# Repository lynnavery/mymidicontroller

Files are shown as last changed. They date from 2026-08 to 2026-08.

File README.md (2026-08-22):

# mymidicontroller
Simple 9 knob 10 key midi controller design using teensy and no mux/adc expanders

## Mockup

## BOM
| Qty | Part |
|---|---|
| 1 | Teensy 4.1 with headers |
| 2 | Custom PCB
| 1 | Jumper wires Female/Male 300mm pack of 40 |
| 1 | Strip of standard headers (2.54mm) for 22 total
| 1 | USB A to Micro-B cable |
| 9 | 10K linear pot PTV09A-4020U-B103 |
| 10 | Cherry MX/knockoff switch (any color) |
| 10 | Keycaps |
| 1 | 0.96in OLED I2C 4-pin white character display |
| 1 | Enclosure and front panel (3d printed) |

If I decide to do an expander for the extra teensy io
| Qty | Part |
|---|---|
| 1 | Panel-mount D-sub or aviation connector |
| 6 | Series resistors 220ohm-1k for expander lines |

## Circuit diagram



## References
- https://www.pjrc.com/teensy/td_midi.html
- Library for teensy midi controllers https://github.com/joshnishikawa/MIDIcontroller
- another midi library for teensy https://tomashg.com/?p=854
- another midi library https://tttapa.github.io/Control-Surface/Doxygen/index.html

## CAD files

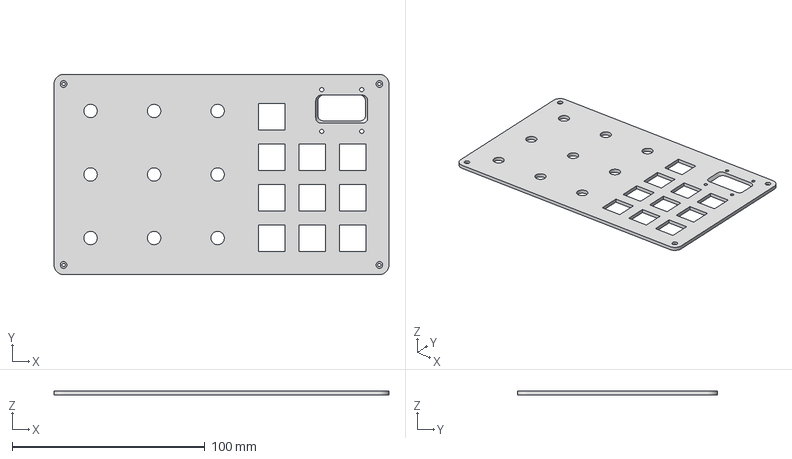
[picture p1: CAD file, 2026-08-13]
3d/faceplate-2.3mf
174.0 x 104.0 x 2.20 mm

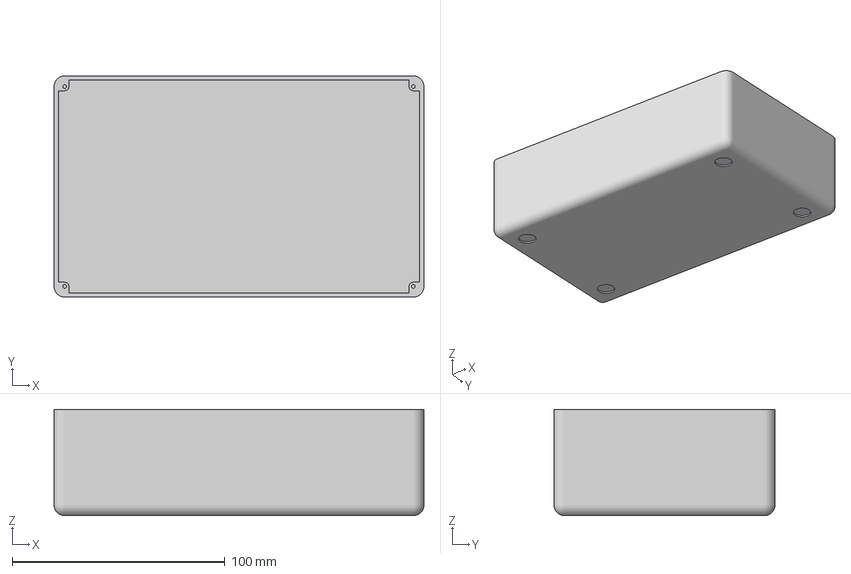
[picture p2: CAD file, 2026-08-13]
3d/mymidi body.3mf
174.0 x 104.0 x 50.0 mm

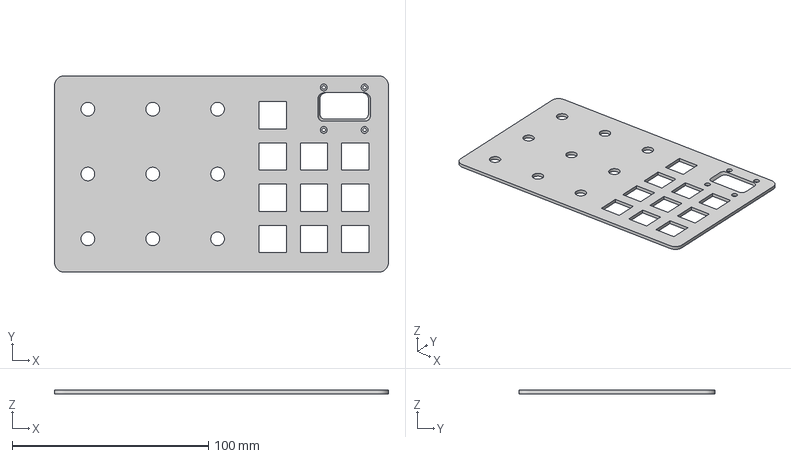
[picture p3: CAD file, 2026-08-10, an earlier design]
3d/mymidicontroller-rev2.3mf
170.0 x 100.0 x 2.00 mm

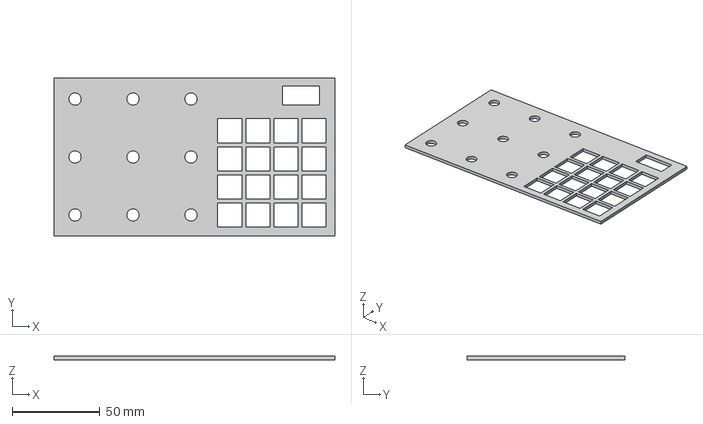
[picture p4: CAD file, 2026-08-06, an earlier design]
3d/mymidicontroller.3mf
160.0 x 90.0 x 2.00 mm

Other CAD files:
3d/faceplate.3mf
3d/mymidicontroller-rev3.3mf
3d/mymidicontroller-rev1.3mf
3d/faceplate-rev4.f3d
3d/mymidi body.stl
3d/mymidicontroller.f3d
3d/mymidicontrollerrev3.stl

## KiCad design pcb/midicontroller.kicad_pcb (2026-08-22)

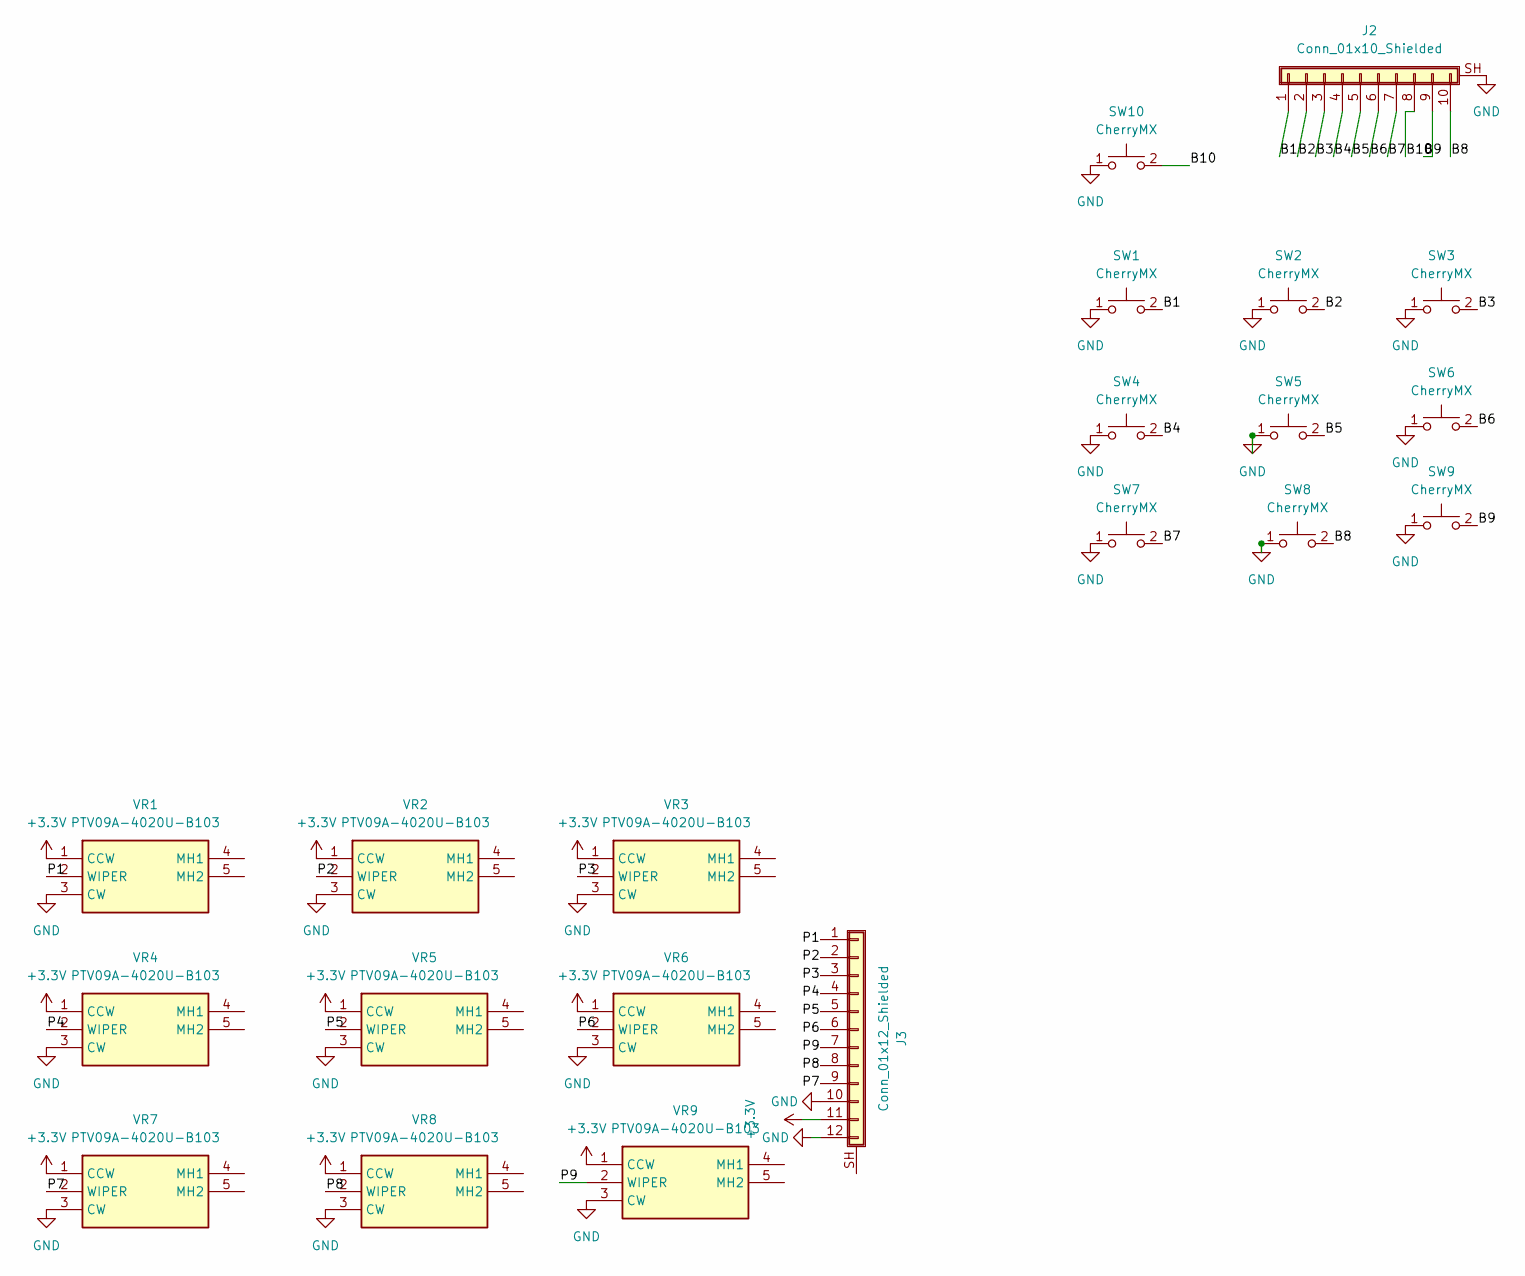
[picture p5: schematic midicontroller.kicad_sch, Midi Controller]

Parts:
J2: Conn_01x10_Shielded; PinHeader_1x11_P2.54mm_Vertical
J3: Conn_01x12_Shielded; PinHeader_1x12_P2.54mm_Vertical
SW1, SW2, SW3, SW4, SW5, SW6, SW7, SW8, SW9, SW10: CherryMX; SW_Cherry_MX_1.00u_PCB
VR1, VR2, VR3, VR4, VR5, VR6, VR7, VR8, VR9: PTV09A-4020U-B103; Manufacturer_Part_Number PTV09A-4020U-B103; Mouser Part Number 652-PTV09A-4020UB103

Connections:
+3.3V: J3.11, VR1.1 (CCW), VR2.1 (CCW), VR3.1 (CCW), VR4.1 (CCW), VR5.1 (CCW), VR6.1 (CCW), VR7.1 (CCW), VR8.1 (CCW), VR9.1 (CCW)
/B1: J2.1, SW1.2
/B2: J2.2, SW2.2
/B3: J2.3, SW3.2
/B4: J2.4, SW4.2
/B5: J2.5, SW5.2
/B6: J2.6, SW6.2
/B7: J2.7, SW7.2
/B8: J2.10, SW8.2
/B9: J2.9, SW9.2
/B10: J2.8, SW10.2
/P1: J3.1, VR1.2 (WIPER)
/P2: J3.2, VR2.2 (WIPER)
/P3: J3.3, VR3.2 (WIPER)
/P4: J3.4, VR4.2 (WIPER)
/P5: J3.5, VR5.2 (WIPER)
/P6: J3.6, VR6.2 (WIPER)
/P7: J3.9, VR7.2 (WIPER)
/P8: J3.8, VR8.2 (WIPER)
/P9: J3.7, VR9.2 (WIPER)
GND: J2.SH (Shield), J3.10, J3.12, SW1.1, SW2.1, SW3.1, SW4.1, SW5.1, SW6.1, SW7.1, SW8.1, SW9.1, SW10.1, VR1.3 (CW), VR2.3 (CW), VR3.3 (CW), VR4.3 (CW), VR5.3 (CW), VR6.3 (CW), VR7.3 (CW), VR8.3 (CW), VR9.3 (CW)

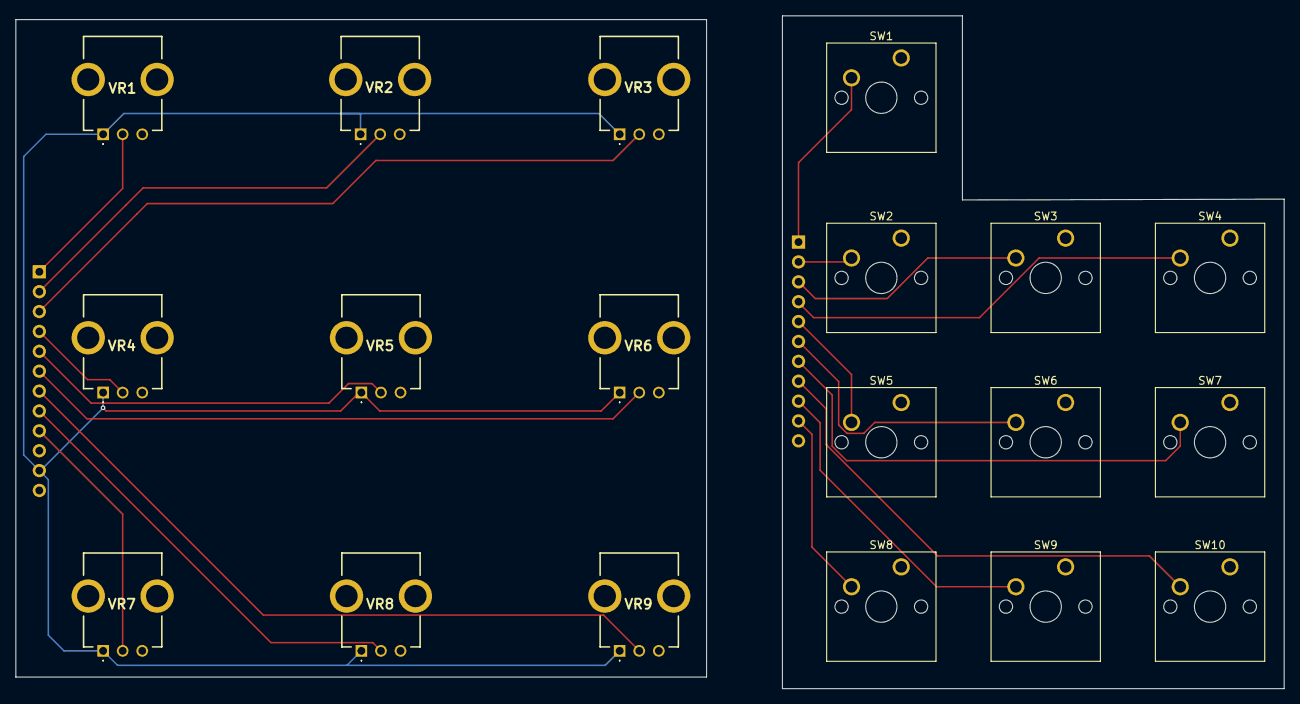
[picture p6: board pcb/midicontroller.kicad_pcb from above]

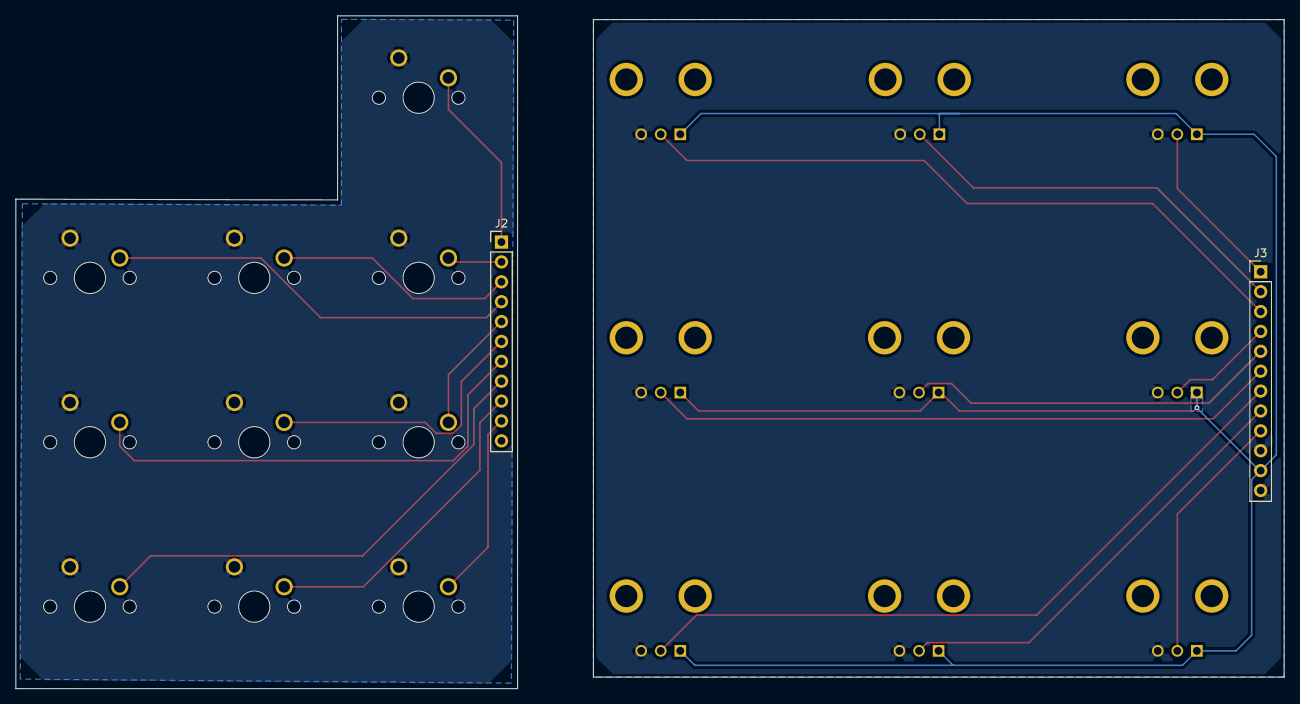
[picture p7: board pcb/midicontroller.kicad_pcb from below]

Board: 2 copper layers, 162.0 x 86.0 mm, 21 parts (2 on the bottom side), 21 nets.

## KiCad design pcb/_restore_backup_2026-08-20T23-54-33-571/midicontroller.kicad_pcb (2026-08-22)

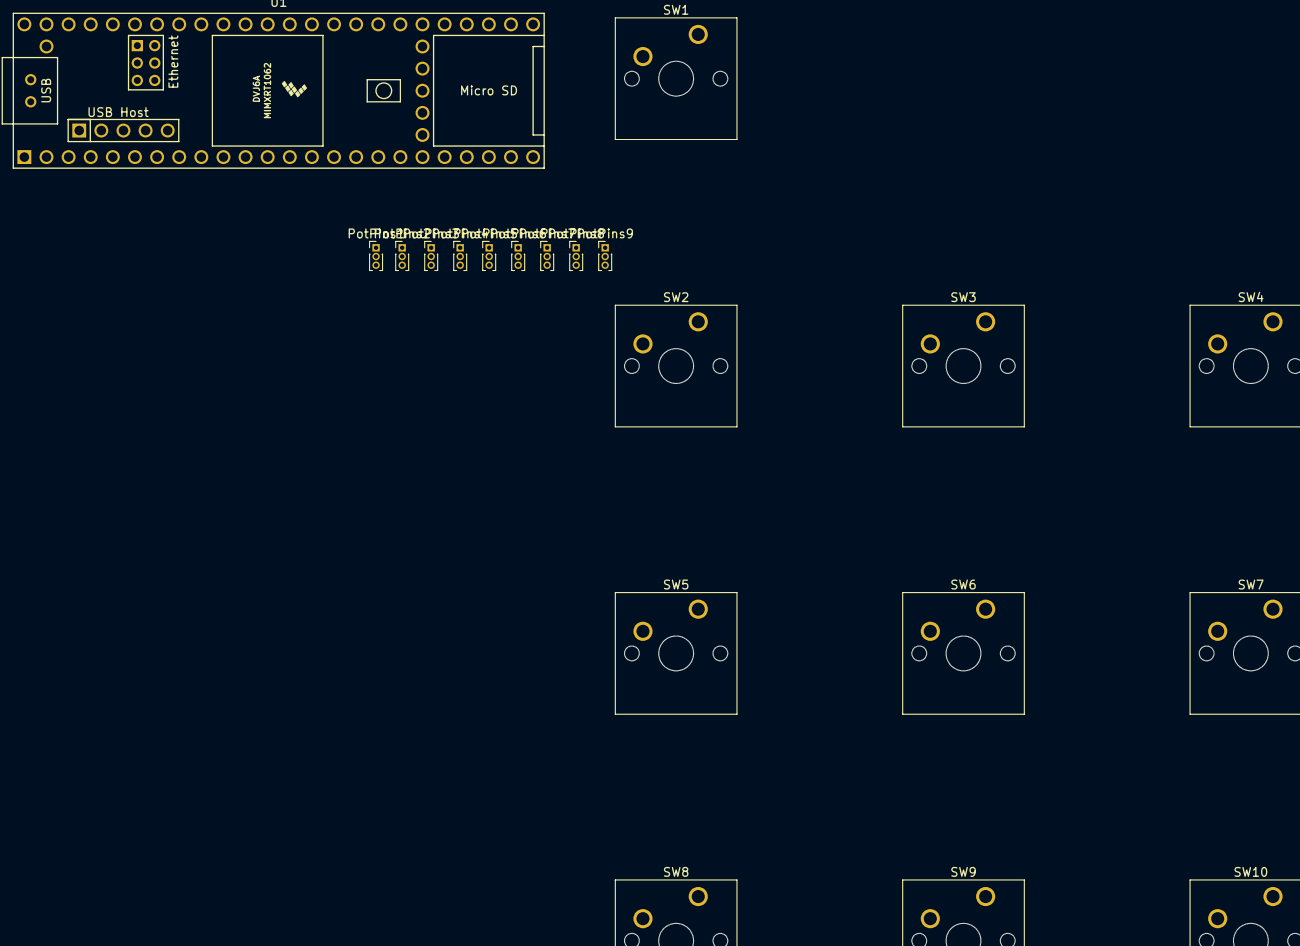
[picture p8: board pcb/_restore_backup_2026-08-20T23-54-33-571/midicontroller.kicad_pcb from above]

Board: 2 copper layers, 20 parts (0 on the bottom side), 20 nets, no tracks yet.

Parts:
PotPins1, PotPins2, PotPins3, PotPins4, PotPins5, PotPins6, PotPins7, PotPins8, PotPins9: PinHeader_1x03_P1.00mm_Vertical
SW1, SW2, SW3, SW4, SW5, SW6, SW7, SW8, SW9, SW10: CherryMX; SW_Cherry_MX_1.00u_PCB
U1: Teensy4.1; Teensy41

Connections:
+3.3V: PotPins1.1 (Pot3v), PotPins2.1 (Pot3v), PotPins3.1 (Pot3v), PotPins4.1 (Pot3v), PotPins5.1 (Pot3v), PotPins6.1 (Pot3v), PotPins7.1 (Pot3v), PotPins8.1 (Pot3v), PotPins9.1 (Pot3v), U1.48 (VIN)
/B2: SW1.2, U1.3 (1_TX1_CTX2_MISO1)
/B3: SW2.2, U1.4 (2_OUT2)
/B4: SW3.2, U1.5 (3_LRCLK2)
/B5: SW4.2, U1.6 (4_BCLK2)
/B6: SW5.2, U1.7 (5_IN2)
/B7: SW6.2, U1.8 (6_OUT1D)
/B8: SW7.2, U1.9 (7_RX2_OUT1A)
/B9: SW8.2, U1.10 (8_TX2_IN1)
/B10: SW9.2, U1.11 (9_OUT1C)
/P1: PotPins1.2 (PotWiper), U1.30 (38_CS1_IN1)
/P2: PotPins3.2 (PotWiper), U1.31 (39_MISO1_OUT1A)
/P3: PotPins4.2 (PotWiper), U1.32 (40_A16)
/P5: PotPins5.2 (PotWiper), U1.36 (14_A0_TX3_SPDIF_OUT)
/P6: PotPins6.2 (PotWiper), U1.37 (15_A1_RX3_SPDIF_IN)
/P7: PotPins7.2 (PotWiper), U1.38 (16_A2_RX4_SCL1)
/P8: PotPins8.2 (PotWiper), U1.39 (17_A3_TX4_SDA1)
/P9: PotPins9.2 (PotWiper), U1.42 (20_A6_TX5_LRCLK1)
GND: PotPins1.3 (PotGND), PotPins2.3 (PotGND), PotPins3.3 (PotGND), PotPins4.3 (PotGND), PotPins5.3 (PotGND), PotPins6.3 (PotGND), PotPins7.3 (PotGND), PotPins8.3 (PotGND), PotPins9.3 (PotGND), SW1.1, SW2.1, SW3.1, SW4.1, SW5.1, SW6.1, SW7.1, SW8.1, SW9.1, SW10.1, U1.47 (GND)
P4: PotPins2.2 (PotWiper), U1.33 (41_A17)

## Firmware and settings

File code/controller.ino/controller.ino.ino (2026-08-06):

#include <Wire.h>
#include <Adafruit_GFX.h>
#include <Adafruit_SSD1306.h>

#define SCREEN_WIDTH 128
#define SCREEN_HEIGHT 64
#define OLED_ADDR 0x3C   // try 0x3D if nothing appears
#define MIDI_CHANNEL 1
#define POT_PIN 14
#define CC_NUMBER 1

Adafruit_SSD1306 display(SCREEN_WIDTH, SCREEN_HEIGHT, &Wire, -1);

int lastSent = -1;

void setup() {
  Serial.begin(9600);
  Wire.begin();   // Teensy 4.1 default: SDA=18, SCL=19
  analogReadResolution(10);

  if (!display.begin(SSD1306_SWITCHCAPVCC, OLED_ADDR)) {
    Serial.println("OLED not found - check wiring and address");
    while (true);   // halt so the error is obvious
  }

  display.clearDisplay();
  display.setTextSize(2);
  display.setTextColor(SSD1306_WHITE);
  display.display();   // nothing shows until this is called
}

void loop() {
  int raw = analogRead(POT_PIN);
  int midi = map(raw, 0, 1023, 0, 127);
  if (midi!= lastSent) {
    usbMIDI.sendControlChange(CC_NUMBER, midi, MIDI_CHANNEL);
    lastSent = midi;

    display.clearDisplay();

    display.setTextSize(1);
    display.setCursor(0, 0);
    display.print("Sending to CC ");
    display.print(CC_NUMBER);

    display.setTextSize(1.5);
    display.setCursor(0, 42);
    display.print("scaled to cc: ");
    display.print(midi);

    display.display();

    Serial.print(raw);
    Serial.print(" -> ");
    Serial.println(midi);
  }
  while (usbMIDI.read()) {}
  delay(5);
}

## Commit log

2026-08-02 Revise README with project details and BOM
    Updated project description and added details about the concept, BOM, circuit diagram, and future enhancements.
2026-08-02 Revise README with mockup and BOM updates
    Updated README with new sections and formatting changes.
2026-08-03 Revise README with project updates and BOM details
    Updated project details, added components to BOM, and refined usage and references sections.
2026-08-07 moved files
    [mymidicontroller-rev1.3mf, mymidicontroller.3mf]
2026-08-10 new added screws and change screen size
    [mymidicontroller-rev1.3mf, mymidicontroller-rev2.3mf, mymidicontroller.3mf]
2026-08-13 fuck stl
    [mymidi body.3mf, mymidicontroller-rev3.3mf]
2026-08-13 fixed screw
    [faceplate-rev4.f3d]
2026-08-22 added pcb
    [midicontroller.kicad_pcb, midicontroller.kicad_sch, temp-freerouting.dsn]
2026-08-22 Revise README with new project details and BOM
    Updated project description, BOM, and references.
